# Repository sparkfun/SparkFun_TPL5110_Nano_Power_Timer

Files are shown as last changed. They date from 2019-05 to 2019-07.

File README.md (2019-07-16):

SparkFun TPL5110 Nano Power Timer
========================================

SparkFun Nano Power Switch

[*SparkFun Nano Power Switch (PRT-15353)*](https://www.sparkfun.com/products/15353)

Sometimes we want our projects on, but sometimes we want to turn them off for a while to save power. The SparkFun Nano Power Timer will run while only consuming minimal power (approximately 35nA) and turn your project on after a set amount of time. When you are done polling your sensors, posting data to the web, writing to your logger, or planning world domination, your microcontroller can tell the Nano Power Timer to turn off the power. No more running your microcontroller all day when you only want to read the ambient temperature once per hour.

Repository Contents
-------------------

* **/Documentation** - Data sheets, additional product information
* **/Firmware** - Example code 
* **/Hardware** - Eagle design files (.brd, .sch)
* **/Production** - Production panel files (.brd)

Documentation
--------------
* **[Hookup Guide](https://learn.sparkfun.com/tutorials/tpl5110-nano-power-timer-hookup-guide)** - Basic hookup guide for the TPL5110 Nano Power Timer.
* **[SparkFun Fritzing repo](https://github.com/sparkfun/Fritzing_Parts)** - Fritzing diagrams for SparkFun products.

License Information
-------------------
This product is _**open source**_! 

Please review the LICENSE.md file for license information. 

If you have any questions or concerns on licensing, please contact technical support on our [SparkFun forums](https://forum.sparkfun.com/viewforum.php?f=152).

Distributed as-is; no warranty is given.

- Your friends at SparkFun.

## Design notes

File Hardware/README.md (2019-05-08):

SparkFun Nano Power Switch Design Files
=====================================

The .sch and .brd files hare are Eagle CAD schematic and PCB design files from SparkFun Electronics.
A freeware version of Eagle can be found [here](http://www.cadsoftusa.com/download-eagle/freeware/).

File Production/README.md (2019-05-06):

SparkFun <PRODUCT NAME> Production Files
=========================================

These are the production files SparkFun uses for printing PCBs.

License Information
-------------------
This product is open source! 

The hardware is released under [Creative Commons ShareAlike 4.0 International](https://creativecommons.org/licenses/by-sa/4.0/).

Please use, reuse, and modify these files as you see fit. Please maintain attribution to SparkFun Electronics and release anything derivative under the same license.

Distributed as-is; no warranty is given.

- Your friends at SparkFun.

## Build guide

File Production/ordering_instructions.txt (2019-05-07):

panel size, 143x195mm
PCB thickness, 1.6mm
number of layers, 2
soldermask color, Red
silkscreen color, White
oz copper, 1oz
finish, HASL lead free
stencils, top+bottom
pcs per panel, 35
min trace width, 0.203200mm / 0.008000in
min drill size, 0.381000mm / 0.015000in

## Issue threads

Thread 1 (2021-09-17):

tpl5110 issue with time interval

MuhammadAsifSaeed, 2021-09-17:
Hello everyone!

I am using nano power timer according to the hookup guide of sparkfun for the last 2 years. Initially i was using it with arduino to increase the battery life and i had set the time interval 15 min. It worked fine, very fine.

this year i have a project and i am using tpl5110 with raspberry pi. nano power timer is supposed to wake up the raspberrry pi after 2 hours, but its not doing the job. Note: if set the time interval 15 min, it works fine.

Need your help.

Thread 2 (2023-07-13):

Revision Suggestion: Adding a Built-In Schottky Diode

bboyho, 2023-07-13:
### Subject of the issue
Users sometimes connect a second power source to their microcontroller's USB for uploading code without a Schottky diode between the Arduino's VIN and the TPL5110 's VOUT. The TPL5110 can be damaged from the conflicting voltages.

### Revision Suggestion
If there is time for a revision, it could be useful to add a built in Schottky diode on the VOUT line to prevent this from happening. Maybe add a jumper on the back for users that want to bypass the diode as well.

roblatour, 2023-08-11:
+1 for this recommendation

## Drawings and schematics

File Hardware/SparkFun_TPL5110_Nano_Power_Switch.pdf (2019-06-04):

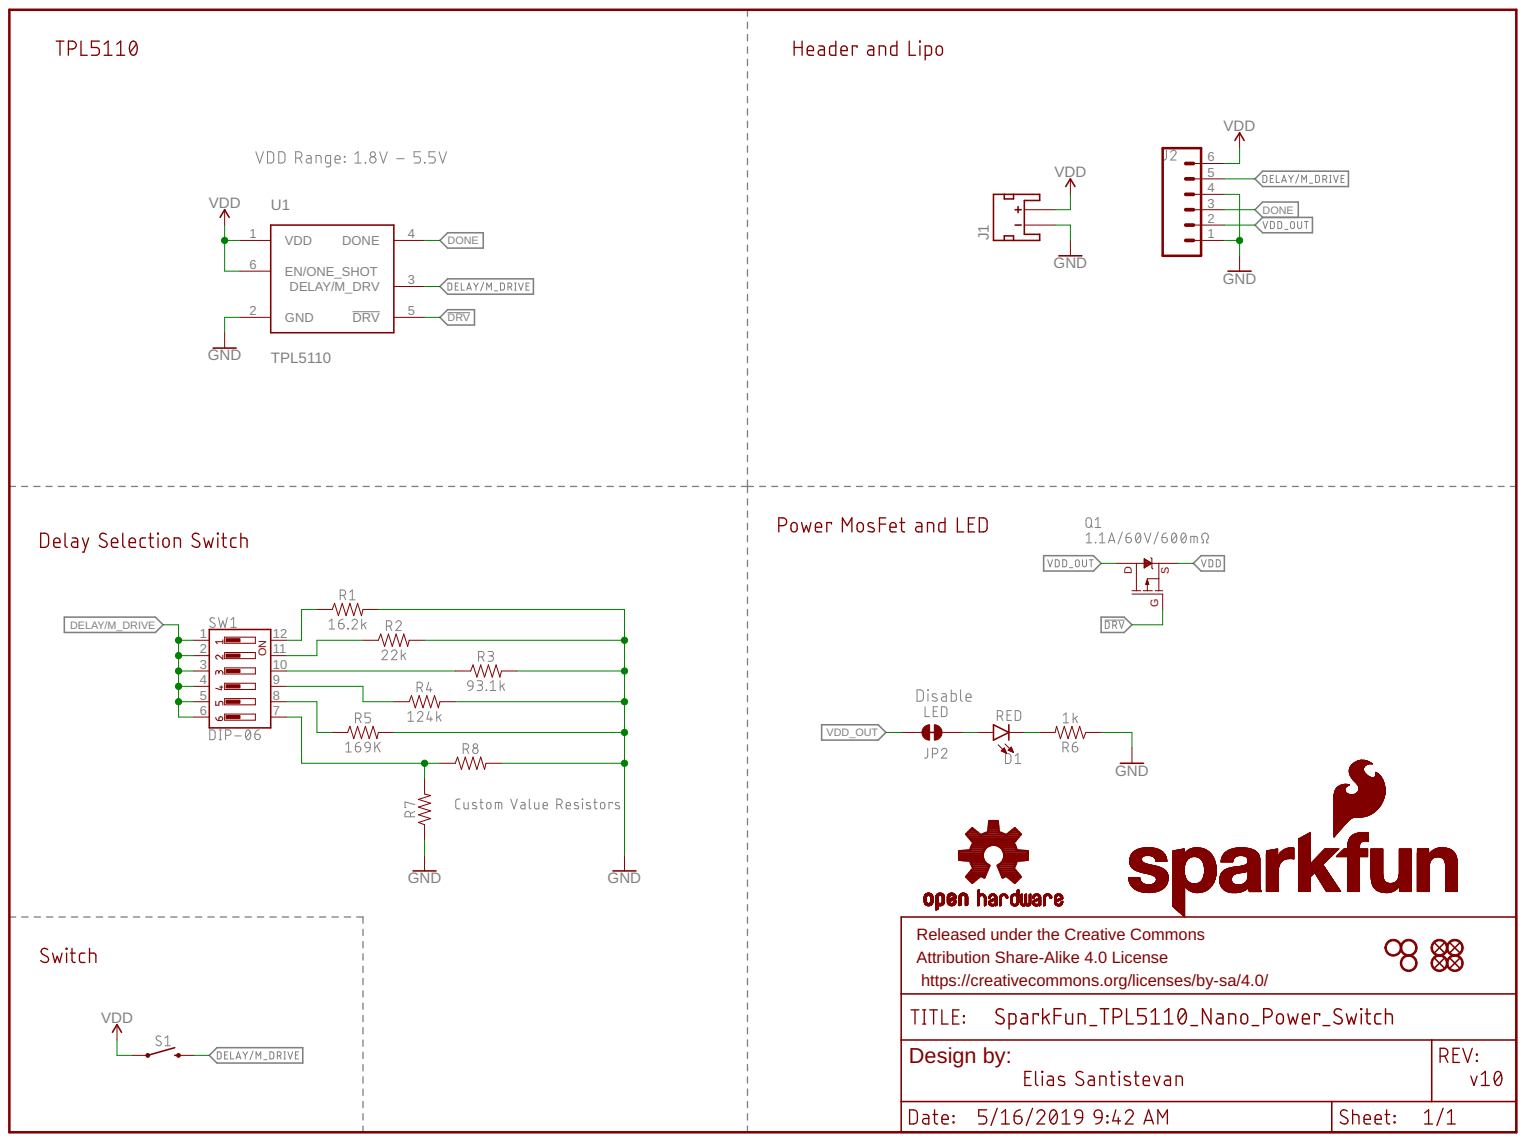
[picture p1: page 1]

Released under the Creative Commons
Attribution Share-Alike 4.0 License
https://creativecommons.org/licenses/by-sa/4.0/

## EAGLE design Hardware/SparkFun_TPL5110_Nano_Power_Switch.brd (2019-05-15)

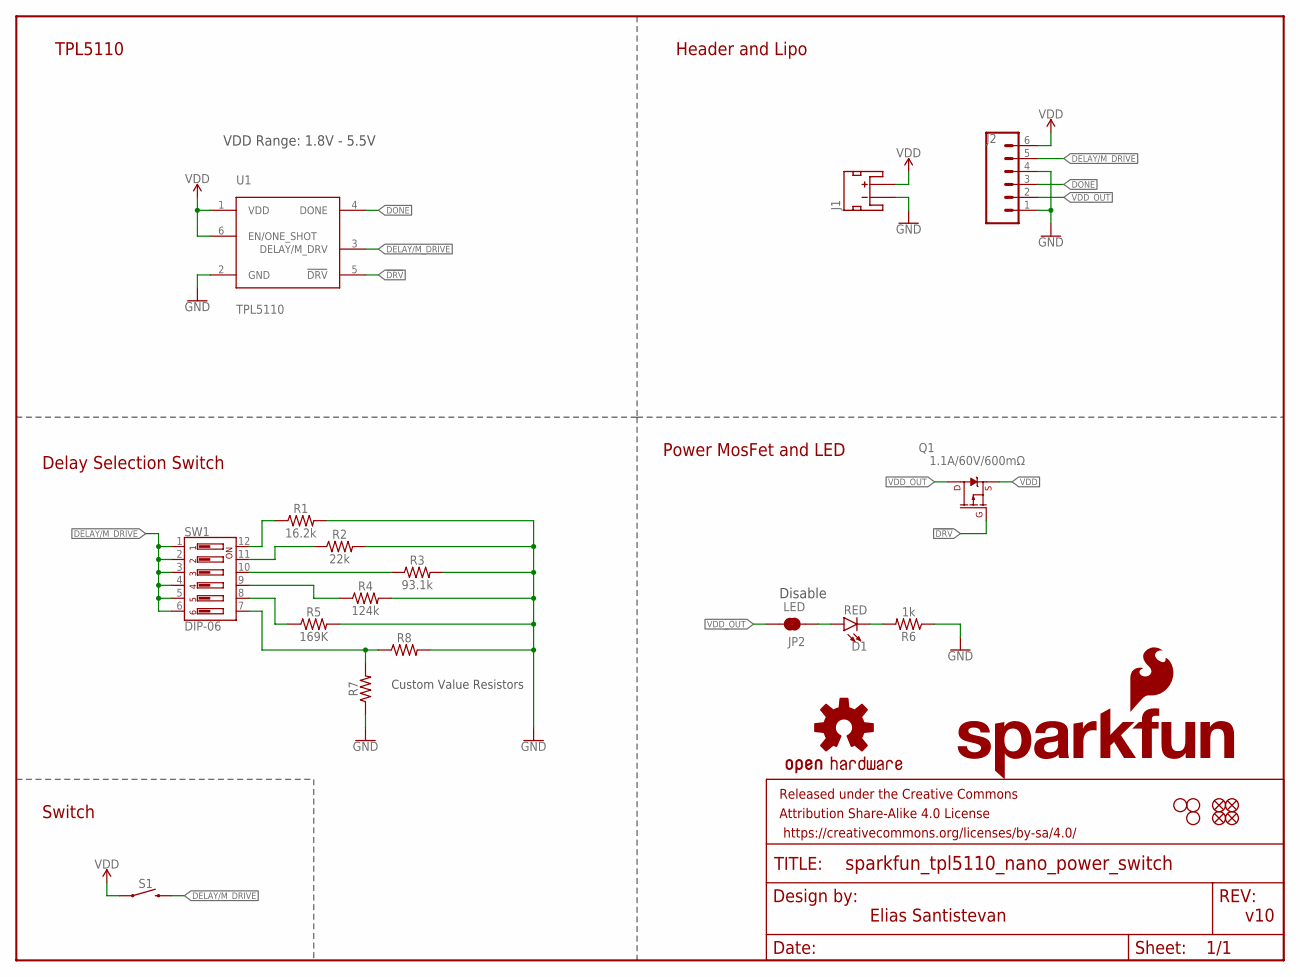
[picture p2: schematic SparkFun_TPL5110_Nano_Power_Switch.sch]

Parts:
D1: RED; LED-0603
FD1, FD2, FD3, FD4: FIDUCIALUFIDUCIAL; FIDUCIAL-MICRO
FRAME1: FRAME-LETTER; CREATIVE_COMMONS
H1, H2, H4: STAND-OFFTIGHT; STAND-OFF-TIGHT
J1: JST_2MM_MALE; JST-2-SMD
J2: CONN_06NO_SILK_NO_POP; 1X06_NO_SILK
JP2: LED; SMT-JUMPER_2_NC_TRACE_SILK
LOGO1: SFE_LOGO_NAME.1_INCH; SFE_LOGO_NAME_.1
LOGO2: OSHW-LOGOS; OSHW-LOGO-S
LOGO3: SFE_LOGO_FLAME.1_INCH; SFE_LOGO_FLAME_.1
Q1: 1.1A/60V/600mΩ; SOT23-3
R1: 16.2k; 0603
R2: 22k; 0603
R3: 93.1k; 0603
R4: 124k; 0603
R5: 169K; 0603
R6: 1k; 0603
R7: 0603
R8: AXIAL-0.3
S1: MOMENTARY-SWITCH-SPST-SMD-5.2MM-TALL; TACTILE_SWITCH_SMD_5.2MM
SW1: DIP-06; DIPSWITCH-06-SMD
U1: TPL5110; SOT23-6

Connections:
!DRV: Q1.1 (G), U1.5 (!DRV)
DELAY/M_DRIVE: J2.5, S1.3 (2), SW1.1, SW1.2, SW1.3, SW1.4, SW1.5, SW1.6, U1.3 (DELAY/M_DRV)
DONE: J2.3, U1.4 (DONE)
GND: J1.1 (-), J2.1, J2.4, R1.2, R2.2, R3.2, R4.2, R5.2, R6.1, R7.1, R8.P$2 (2), U1.2 (GND)
unnamed: D1.C, R6.2
unnamed: R1.1, SW1.12
unnamed: R2.1, SW1.11
unnamed: R3.1, SW1.10
unnamed: R4.1, SW1.9
unnamed: R5.1, SW1.8
unnamed: R7.2, R8.P$1 (1), SW1.7
unnamed: D1.A, JP2.1
VDD: J1.2 (+), J2.6, Q1.2 (S), S1.1, U1.1 (VDD), U1.6 (EN/ONE_SHOT)
VDD_OUT: J2.2, JP2.2, Q1.3 (D)

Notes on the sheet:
Elias Santistevan
v10
VDD Range: 1.8V - 5.5V
TPL5110
Header and Lipo
Power MosFet and LED
Delay Selection Switch
Switch
Disable
Custom Value Resistors

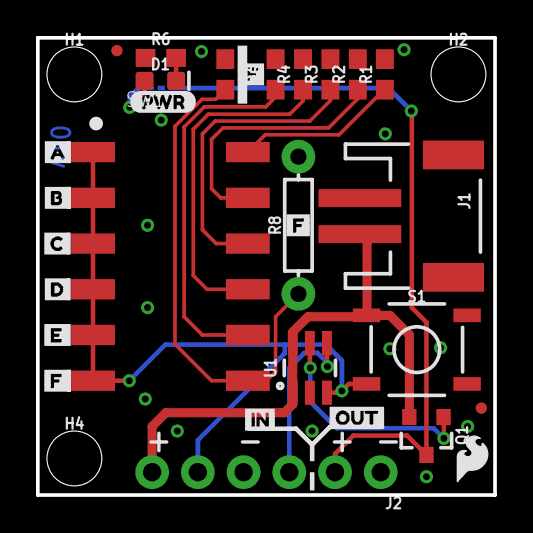
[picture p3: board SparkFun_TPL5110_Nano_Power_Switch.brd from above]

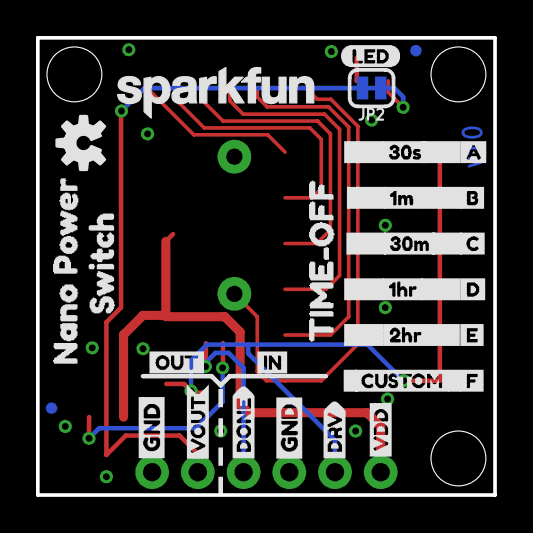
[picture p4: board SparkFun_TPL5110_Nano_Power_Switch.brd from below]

Board: 2 copper layers, 25.4 x 25.4 mm, 62 parts (29 on the bottom side), 14 nets.

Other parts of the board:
U$1: DONE0
U$2, U$4: GND-03
U$3: VOUT0
U$5: VDD0
U$6: NANO_POWER0
U$7: SWITCH0
U$8: 1M0
U$9: 30S4
U$10: 30M2
U$11: 1HR3
U$12: 2HR4
U$13: LED0
U$14: CUSTOM0
U$15: TIME#OFF0
U$16: DRV0
U$17, U$25: A0
U$18, U$26: B1
U$19, U$27: C2
U$20, U$28: D3
U$21, U$29: E4
U$22, U$23, U$24, U$30: F5
U$31, U$33: IN0
U$32, U$34: OUT1
U$35: PWR-()-03

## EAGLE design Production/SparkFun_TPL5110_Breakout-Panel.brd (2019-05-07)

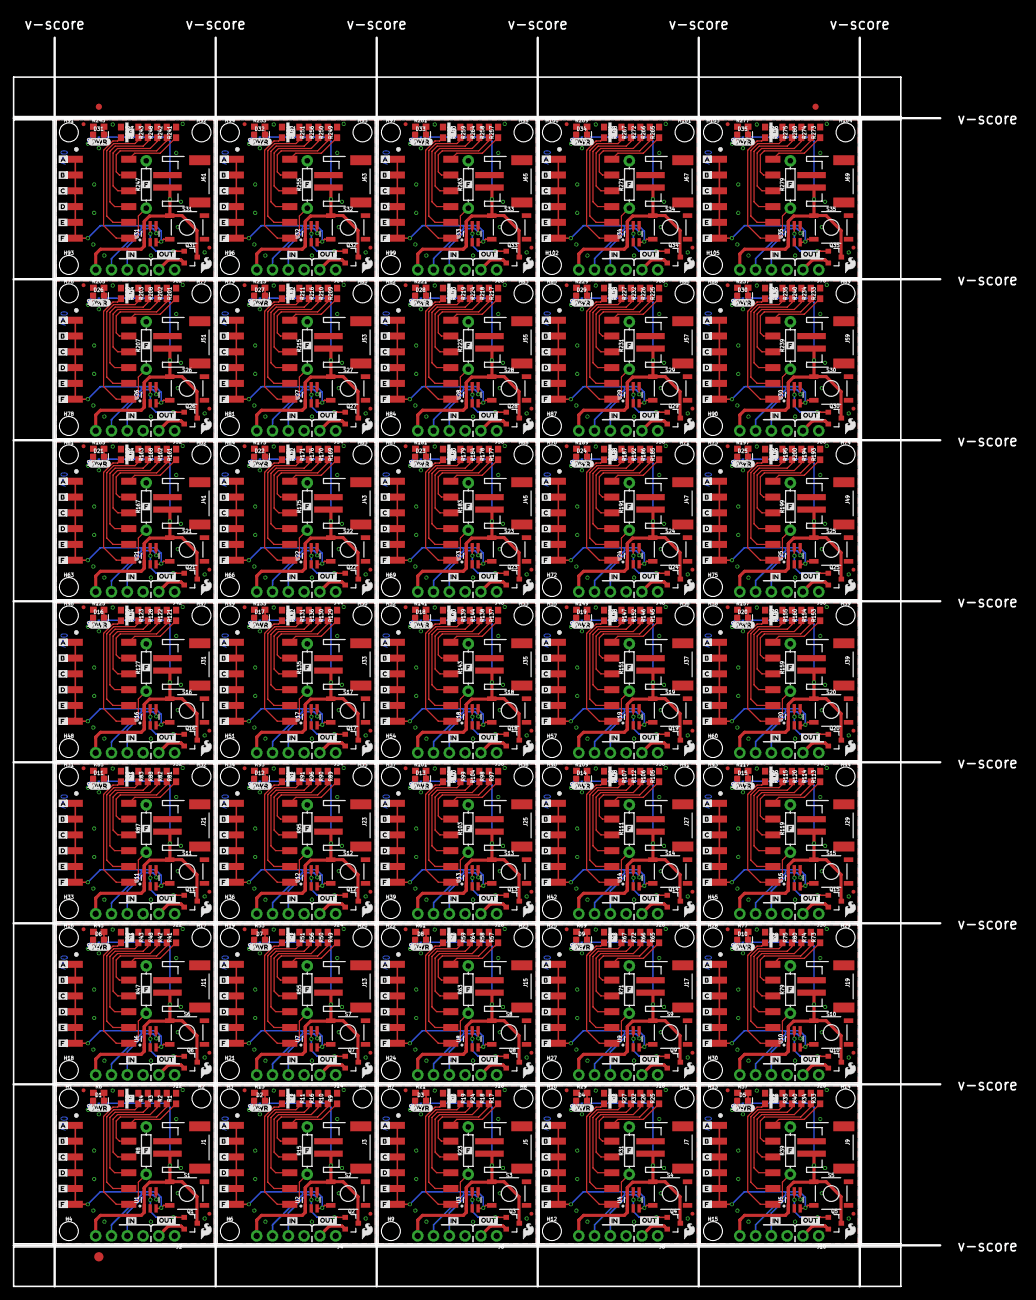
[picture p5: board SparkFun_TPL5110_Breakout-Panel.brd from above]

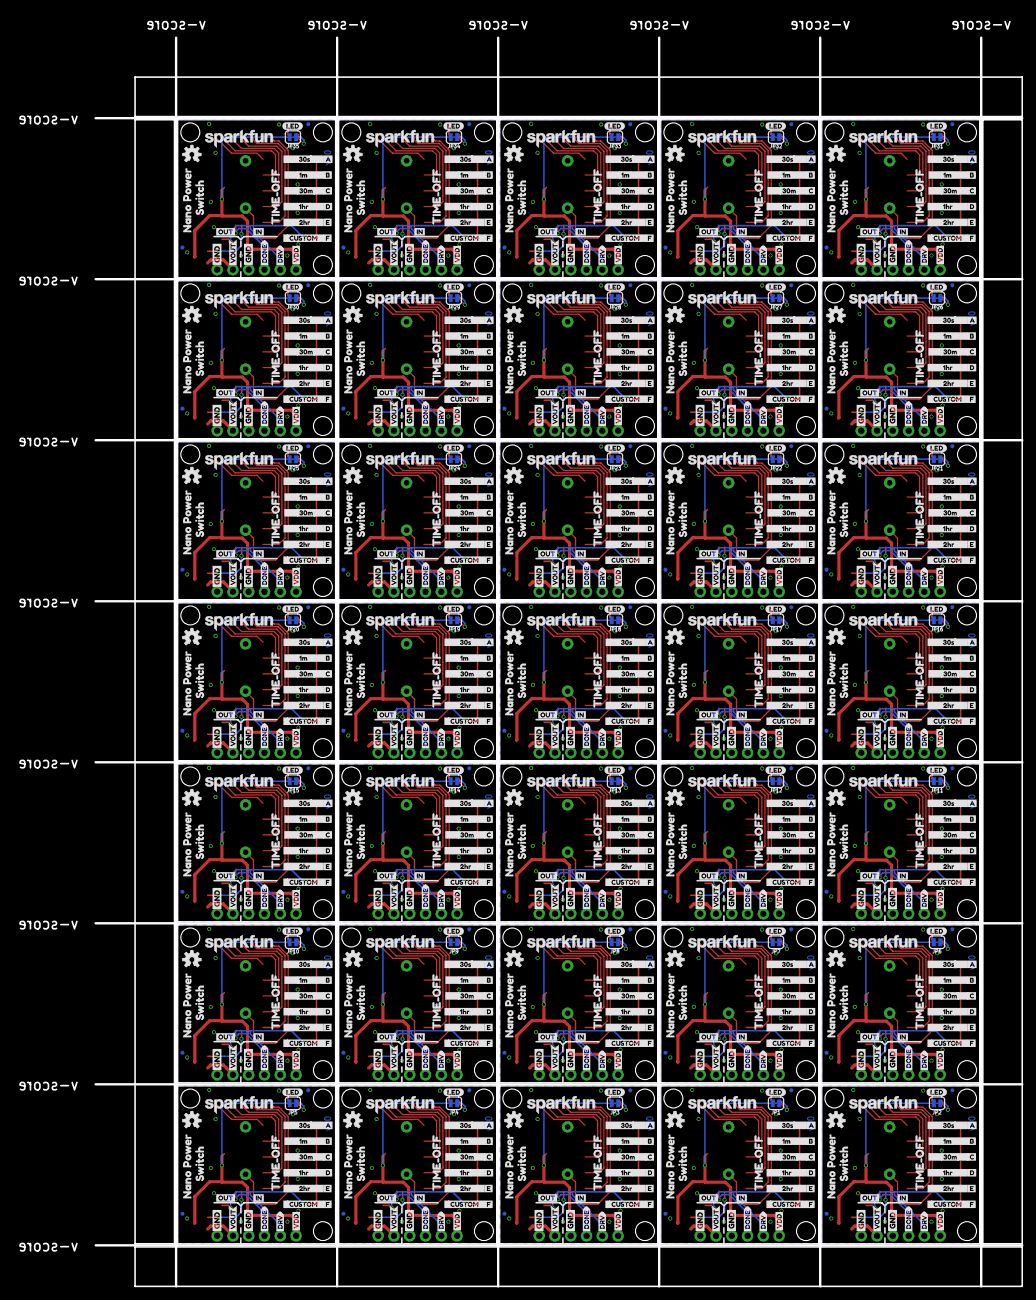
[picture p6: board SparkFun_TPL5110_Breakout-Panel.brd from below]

Board: 2 copper layers, 149.1 x 200.9 mm, 2138 parts (1015 on the bottom side), 490 nets.

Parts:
D1, D2, D3, D4, D5, D6, D7, D8, D9, D10, D11, D12, D13, D14, D15, D16, D17, D18, D19, D20, D21, D22, D23, D24, D25, D26, D27, D28, D29, D30, D31, D32, D33, D34, D35: RED; LED-0603
E$1, E$2: FIDUCIAL-1X2
E$3: FIDUCIAL-1.5X3
FD1, FD2, FD3, FD4, FD5, FD6, FD7, FD8, FD9, FD10, FD11, FD12, FD13, FD14, FD15, FD16, FD17, FD18, FD19, FD20, FD21, FD22, FD23, FD24, FD25, FD26, FD27, FD28, FD29, FD30, FD31, FD32, FD33, FD34, FD35, FD36, FD37, FD38, FD39, FD40, FD41, FD42, FD43, FD44, FD45, FD46, FD47, FD48, FD49, FD50, FD51, FD52, FD53, FD54, FD55, FD56, FD57, FD58, FD59, FD60, FD61, FD62, FD63, FD64, FD65, FD66, FD67, FD68, FD69, FD70, FD71, FD72, FD73, FD74, FD75, FD76, FD77, FD78, FD79, FD80, FD81, FD82, FD83, FD84, FD85, FD86, FD87, FD88, FD89, FD90, FD91, FD92, FD93, FD94, FD95, FD96, FD97, FD98, FD99, FD100, FD101, FD102, FD103, FD104, FD105, FD106, FD107, FD108, FD109, FD110, FD111, FD112, FD113, FD114, FD115, FD116, FD117, FD118, FD119, FD120, FD121, FD122, FD123, FD124, FD125, FD126, FD127, FD128, FD129, FD130, FD131, FD132, FD133, FD134, FD135, FD136, FD137, FD138, FD139, FD140: FIDUCIALUFIDUCIAL; FIDUCIAL-MICRO
H1, H2, H3, H4, H5, H6, H7, H8, H9, H10, H11, H12, H13, H14, H15, H16, H17, H18, H19, H20, H21, H22, H23, H24, H25, H26, H27, H28, H29, H30, H31, H32, H33, H34, H35, H36, H37, H38, H39, H40, H41, H42, H43, H44, H45, H46, H47, H48, H49, H50, H51, H52, H53, H54, H55, H56, H57, H58, H59, H60, H61, H62, H63, H64, H65, H66, H67, H68, H69, H70, H71, H72, H73, H74, H75, H76, H77, H78, H79, H80, H81, H82, H83, H84, H85, H86, H87, H88, H89, H90, H91, H92, H93, H94, H95, H96, H97, H98, H99, H100, H101, H102, H103, H104, H105: STAND-OFFTIGHT; STAND-OFF-TIGHT
J1, J3, J5, J7, J9, J11, J13, J15, J17, J19, J21, J23, J25, J27, J29, J31, J33, J35, J37, J39, J41, J43, J45, J47, J49, J51, J53, J55, J57, J59, J61, J63, J65, J67, J69: JST-2-SMD
J2, J4, J6, J8, J10, J12, J14, J16, J18, J20, J22, J24, J26, J28, J30, J32, J34, J36, J38, J40, J42, J44, J46, J48, J50, J52, J54, J56, J58, J60, J62, J64, J66, J68, J70: 1X06_NO_SILK
JP1, JP2, JP3, JP4, JP5, JP6, JP7, JP8, JP9, JP10, JP11, JP12, JP13, JP14, JP15, JP16, JP17, JP18, JP19, JP20, JP21, JP22, JP23, JP24, JP25, JP26, JP27, JP28, JP29, JP30, JP31, JP32, JP33, JP34, JP35: LED; SMT-JUMPER_2_NC_TRACE_SILK
LOGO1, LOGO4, LOGO7, LOGO10, LOGO13, LOGO16, LOGO19, LOGO22, LOGO25, LOGO28, LOGO31, LOGO34, LOGO37, LOGO40, LOGO43, LOGO46, LOGO49, LOGO52, LOGO55, LOGO58, LOGO61, LOGO64, LOGO67, LOGO70, LOGO73, LOGO76, LOGO79, LOGO82, LOGO85, LOGO88, LOGO91, LOGO94, LOGO97, LOGO100, LOGO103: SFE_LOGO_NAME.1_INCH; SFE_LOGO_NAME_.1
LOGO2, LOGO5, LOGO8, LOGO11, LOGO14, LOGO17, LOGO20, LOGO23, LOGO26, LOGO29, LOGO32, LOGO35, LOGO38, LOGO41, LOGO44, LOGO47, LOGO50, LOGO53, LOGO56, LOGO59, LOGO62, LOGO65, LOGO68, LOGO71, LOGO74, LOGO77, LOGO80, LOGO83, LOGO86, LOGO89, LOGO92, LOGO95, LOGO98, LOGO101, LOGO104: OSHW-LOGOS; OSHW-LOGO-S
LOGO3, LOGO6, LOGO9, LOGO12, LOGO15, LOGO18, LOGO21, LOGO24, LOGO27, LOGO30, LOGO33, LOGO36, LOGO39, LOGO42, LOGO45, LOGO48, LOGO51, LOGO54, LOGO57, LOGO60, LOGO63, LOGO66, LOGO69, LOGO72, LOGO75, LOGO78, LOGO81, LOGO84, LOGO87, LOGO90, LOGO93, LOGO96, LOGO99, LOGO102, LOGO105: SFE_LOGO_FLAME.1_INCH; SFE_LOGO_FLAME_.1
Q1, Q2, Q3, Q4, Q5, Q6, Q7, Q8, Q9, Q10, Q11, Q12, Q13, Q14, Q15, Q16, Q17, Q18, Q19, Q20, Q21, Q22, Q23, Q24, Q25, Q26, Q27, Q28, Q29, Q30, Q31, Q32, Q33, Q34, Q35: 1.1A/60V/600mΩ; SOT23-3
R1, R9, R17, R25, R33, R41, R49, R57, R65, R73, R81, R89, R97, R105, R113, R121, R129, R137, R145, R153, R161, R169, R177, R185, R193, R201, R209, R217, R225, R233, R241, R249, R257, R265, R273: 16.2k; 0603
R2, R10, R18, R26, R34, R42, R50, R58, R66, R74, R82, R90, R98, R106, R114, R122, R130, R138, R146, R154, R162, R170, R178, R186, R194, R202, R210, R218, R226, R234, R242, R250, R258, R266, R274: 22k; 0603
R3, R16, R24, R32, R40, R48, R56, R64, R72, R80, R88, R96, R104, R112, R120, R128, R136, R144, R152, R160, R168, R176, R184, R192, R200, R208, R216, R224, R232, R240, R248, R256, R264, R272, R280: 93.1k; 0603
R4, R11, R19, R27, R35, R43, R51, R59, R67, R75, R83, R91, R99, R107, R115, R123, R131, R139, R147, R155, R163, R171, R179, R187, R195, R203, R211, R219, R227, R235, R243, R251, R259, R267, R275: 124k; 0603
R5, R12, R20, R28, R36, R44, R52, R60, R68, R76, R84, R92, R100, R108, R116, R124, R132, R140, R148, R156, R164, R172, R180, R188, R196, R204, R212, R220, R228, R236, R244, R252, R260, R268, R276: 169K; 0603
R6, R13, R21, R29, R37, R45, R53, R61, R69, R77, R85, R93, R101, R109, R117, R125, R133, R141, R149, R157, R165, R173, R181, R189, R197, R205, R213, R221, R229, R237, R245, R253, R261, R269, R277: 330; 0603
R7, R14, R22, R30, R38, R46, R54, R62, R70, R78, R86, R94, R102, R110, R118, R126, R134, R142, R150, R158, R166, R174, R182, R190, R198, R206, R214, R222, R230, R238, R246, R254, R262, R270, R278: 0603
R8, R15, R23, R31, R39, R47, R55, R63, R71, R79, R87, R95, R103, R111, R119, R127, R135, R143, R151, R159, R167, R175, R183, R191, R199, R207, R215, R223, R231, R239, R247, R255, R263, R271, R279: AXIAL-0.3
S1, S2, S3, S4, S5, S6, S7, S8, S9, S10, S11, S12, S13, S14, S15, S16, S17, S18, S19, S20, S21, S22, S23, S24, S25, S26, S27, S28, S29, S30, S31, S32, S33, S34, S35: MOMENTARY-SWITCH-SPST-SMD-5.2MM-TALL; TACTILE_SWITCH_SMD_5.2MM
SW1, SW2, SW3, SW4, SW5, SW6, SW7, SW8, SW9, SW10, SW11, SW12, SW13, SW14, SW15, SW16, SW17, SW18, SW19, SW20, SW21, SW22, SW23, SW24, SW25, SW26, SW27, SW28, SW29, SW30, SW31, SW32, SW33, SW34, SW35: DIP-06; DIPSWITCH-06-SMD
U1, U2, U3, U4, U5, U6, U7, U8, U9, U10, U11, U12, U13, U14, U15, U16, U17, U18, U19, U20, U21, U22, U23, U24, U25, U26, U27, U28, U29, U30, U31, U32, U33, U34, U35: TPL5110; SOT23-6
U$1, U$42, U$77, U$112, U$147, U$182, U$217, U$252, U$287, U$322, U$357, U$392, U$427, U$462, U$497, U$532, U$567, U$602, U$637, U$672, U$707, U$742, U$777, U$812, U$847, U$882, U$917, U$952, U$987, U$1022, U$1057, U$1092, U$1127, U$1162, U$1197: DONE0
U$2, U$4, U$36, U$38, U$71, U$73, U$106, U$108, U$141, U$143, U$176, U$178, U$211, U$213, U$246, U$248, U$281, U$283, U$316, U$318, U$351, U$353, U$386, U$388, U$421, U$423, U$456, U$458, U$491, U$493, U$526, U$528, U$561, U$563, U$596, U$598, U$631, U$633, U$666, U$668, U$701, U$703, U$736, U$738, U$771, U$773, U$806, U$808, U$841, U$843, U$876, U$878, U$911, U$913, U$946, U$948, U$981, U$983, U$1016, U$1018, U$1051, U$1053, U$1086, U$1088, U$1121, U$1123, U$1156, U$1158, U$1191, U$1193: GND-03
U$3, U$43, U$78, U$113, U$148, U$183, U$218, U$253, U$288, U$323, U$358, U$393, U$428, U$463, U$498, U$533, U$568, U$603, U$638, U$673, U$708, U$743, U$778, U$813, U$848, U$883, U$918, U$953, U$988, U$1023, U$1058, U$1093, U$1128, U$1163, U$1198: VOUT0
U$5, U$37, U$72, U$107, U$142, U$177, U$212, U$247, U$282, U$317, U$352, U$387, U$422, U$457, U$492, U$527, U$562, U$597, U$632, U$667, U$702, U$737, U$772, U$807, U$842, U$877, U$912, U$947, U$982, U$1017, U$1052, U$1087, U$1122, U$1157, U$1192: VDD0
U$6, U$68, U$103, U$138, U$173, U$208, U$243, U$278, U$313, U$348, U$383, U$418, U$453, U$488, U$523, U$558, U$593, U$628, U$663, U$698, U$733, U$768, U$803, U$838, U$873, U$908, U$943, U$978, U$1013, U$1048, U$1083, U$1118, U$1153, U$1188, U$1223: NANO_POWER0
U$7, U$69, U$104, U$139, U$174, U$209, U$244, U$279, U$314, U$349, U$384, U$419, U$454, U$489, U$524, U$559, U$594, U$629, U$664, U$699, U$734, U$769, U$804, U$839, U$874, U$909, U$944, U$979, U$1014, U$1049, U$1084, U$1119, U$1154, U$1189, U$1224: SWITCH0
U$8, U$59, U$94, U$129, U$164, U$199, U$234, U$269, U$304, U$339, U$374, U$409, U$444, U$479, U$514, U$549, U$584, U$619, U$654, U$689, U$724, U$759, U$794, U$829, U$864, U$899, U$934, U$969, U$1004, U$1039, U$1074, U$1109, U$1144, U$1179, U$1214: 1M0
U$9, U$63, U$98, U$133, U$168, U$203, U$238, U$273, U$308, U$343, U$378, U$413, U$448, U$483, U$518, U$553, U$588, U$623, U$658, U$693, U$728, U$763, U$798, U$833, U$868, U$903, U$938, U$973, U$1008, U$1043, U$1078, U$1113, U$1148, U$1183, U$1218: 30S4
U$10, U$60, U$95, U$130, U$165, U$200, U$235, U$270, U$305, U$340, U$375, U$410, U$445, U$480, U$515, U$550, U$585, U$620, U$655, U$690, U$725, U$760, U$795, U$830, U$865, U$900, U$935, U$970, U$1005, U$1040, U$1075, U$1110, U$1145, U$1180, U$1215: 30M2
U$11, U$61, U$96, U$131, U$166, U$201, U$236, U$271, U$306, U$341, U$376, U$411, U$446, U$481, U$516, U$551, U$586, U$621, U$656, U$691, U$726, U$761, U$796, U$831, U$866, U$901, U$936, U$971, U$1006, U$1041, U$1076, U$1111, U$1146, U$1181, U$1216: 1HR3
U$12, U$62, U$97, U$132, U$167, U$202, U$237, U$272, U$307, U$342, U$377, U$412, U$447, U$482, U$517, U$552, U$587, U$622, U$657, U$692, U$727, U$762, U$797, U$832, U$867, U$902, U$937, U$972, U$1007, U$1042, U$1077, U$1112, U$1147, U$1182, U$1217: 2HR4
U$13, U$40, U$75, U$110, U$145, U$180, U$215, U$250, U$285, U$320, U$355, U$390, U$425, U$460, U$495, U$530, U$565, U$600, U$635, U$670, U$705, U$740, U$775, U$810, U$845, U$880, U$915, U$950, U$985, U$1020, U$1055, U$1090, U$1125, U$1160, U$1195: LED0
U$14, U$39, U$74, U$109, U$144, U$179, U$214, U$249, U$284, U$319, U$354, U$389, U$424, U$459, U$494, U$529, U$564, U$599, U$634, U$669, U$704, U$739, U$774, U$809, U$844, U$879, U$914, U$949, U$984, U$1019, U$1054, U$1089, U$1124, U$1159, U$1194: CUSTOM0
U$15, U$41, U$76, U$111, U$146, U$181, U$216, U$251, U$286, U$321, U$356, U$391, U$426, U$461, U$496, U$531, U$566, U$601, U$636, U$671, U$706, U$741, U$776, U$811, U$846, U$881, U$916, U$951, U$986, U$1021, U$1056, U$1091, U$1126, U$1161, U$1196: TIME#OFF0
U$16, U$44, U$79, U$114, U$149, U$184, U$219, U$254, U$289, U$324, U$359, U$394, U$429, U$464, U$499, U$534, U$569, U$604, U$639, U$674, U$709, U$744, U$779, U$814, U$849, U$884, U$919, U$954, U$989, U$1024, U$1059, U$1094, U$1129, U$1164, U$1199: DRV0
U$17, U$25, U$45, U$53, U$80, U$88, U$115, U$123, U$150, U$158, U$185, U$193, U$220, U$228, U$255, U$263, U$290, U$298, U$325, U$333, U$360, U$368, U$395, U$403, U$430, U$438, U$465, U$473, U$500, U$508, U$535, U$543, U$570, U$578, U$605, U$613, U$640, U$648, U$675, U$683, U$710, U$718, U$745, U$753, U$780, U$788, U$815, U$823, U$850, U$858, U$885, U$893, U$920, U$928, U$955, U$963, U$990, U$998, U$1025, U$1033, U$1060, U$1068, U$1095, U$1103, U$1130, U$1138, U$1165, U$1173, U$1200, U$1208: A0
U$18, U$26, U$46, U$54, U$81, U$89, U$116, U$124, U$151, U$159, U$186, U$194, U$221, U$229, U$256, U$264, U$291, U$299, U$326, U$334, U$361, U$369, U$396, U$404, U$431, U$439, U$466, U$474, U$501, U$509, U$536, U$544, U$571, U$579, U$606, U$614, U$641, U$649, U$676, U$684, U$711, U$719, U$746, U$754, U$781, U$789, U$816, U$824, U$851, U$859, U$886, U$894, U$921, U$929, U$956, U$964, U$991, U$999, U$1026, U$1034, U$1061, U$1069, U$1096, U$1104, U$1131, U$1139, U$1166, U$1174, U$1201, U$1209: B1
U$19, U$27, U$47, U$55, U$82, U$90, U$117, U$125, U$152, U$160, U$187, U$195, U$222, U$230, U$257, U$265, U$292, U$300, U$327, U$335, U$362, U$370, U$397, U$405, U$432, U$440, U$467, U$475, U$502, U$510, U$537, U$545, U$572, U$580, U$607, U$615, U$642, U$650, U$677, U$685, U$712, U$720, U$747, U$755, U$782, U$790, U$817, U$825, U$852, U$860, U$887, U$895, U$922, U$930, U$957, U$965, U$992, U$1000, U$1027, U$1035, U$1062, U$1070, U$1097, U$1105, U$1132, U$1140, U$1167, U$1175, U$1202, U$1210: C2
U$20, U$28, U$48, U$56, U$83, U$91, U$118, U$126, U$153, U$161, U$188, U$196, U$223, U$231, U$258, U$266, U$293, U$301, U$328, U$336, U$363, U$371, U$398, U$406, U$433, U$441, U$468, U$476, U$503, U$511, U$538, U$546, U$573, U$581, U$608, U$616, U$643, U$651, U$678, U$686, U$713, U$721, U$748, U$756, U$783, U$791, U$818, U$826, U$853, U$861, U$888, U$896, U$923, U$931, U$958, U$966, U$993, U$1001, U$1028, U$1036, U$1063, U$1071, U$1098, U$1106, U$1133, U$1141, U$1168, U$1176, U$1203, U$1211: D3
U$21, U$29, U$49, U$57, U$84, U$92, U$119, U$127, U$154, U$162, U$189, U$197, U$224, U$232, U$259, U$267, U$294, U$302, U$329, U$337, U$364, U$372, U$399, U$407, U$434, U$442, U$469, U$477, U$504, U$512, U$539, U$547, U$574, U$582, U$609, U$617, U$644, U$652, U$679, U$687, U$714, U$722, U$749, U$757, U$784, U$792, U$819, U$827, U$854, U$862, U$889, U$897, U$924, U$932, U$959, U$967, U$994, U$1002, U$1029, U$1037, U$1064, U$1072, U$1099, U$1107, U$1134, U$1142, U$1169, U$1177, U$1204, U$1212: E4
U$22, U$23, U$24, U$30, U$50, U$51, U$52, U$58, U$85, U$86, U$87, U$93, U$120, U$121, U$122, U$128, U$155, U$156, U$157, U$163, U$190, U$191, U$192, U$198, U$225, U$226, U$227, U$233, U$260, U$261, U$262, U$268, U$295, U$296, U$297, U$303, U$330, U$331, U$332, U$338, U$365, U$366, U$367, U$373, U$400, U$401, U$402, U$408, U$435, U$436, U$437, U$443, U$470, U$471, U$472, U$478, U$505, U$506, U$507, U$513, U$540, U$541, U$542, U$548, U$575, U$576, U$577, U$583, U$610, U$611, U$612, U$618, U$645, U$646, U$647, U$653, U$680, U$681, U$682, U$688, U$715, U$716, U$717, U$723, U$750, U$751, U$752, U$758, U$785, U$786, U$787, U$793, U$820, U$821, U$822, U$828, U$855, U$856, U$857, U$863, U$890, U$891, U$892, U$898, U$925, U$926, U$927, U$933, U$960, U$961, U$962, U$968, U$995, U$996, U$997, U$1003, U$1030, U$1031, U$1032, U$1038, U$1065, U$1066, U$1067, U$1073, U$1100, U$1101, U$1102, U$1108, U$1135, U$1136, U$1137, U$1143, U$1170, U$1171, U$1172, U$1178, U$1205, U$1206, U$1207, U$1213: F5
U$31, U$33, U$64, U$66, U$99, U$101, U$134, U$136, U$169, U$171, U$204, U$206, U$239, U$241, U$274, U$276, U$309, U$311, U$344, U$346, U$379, U$381, U$414, U$416, U$449, U$451, U$484, U$486, U$519, U$521, U$554, U$556, U$589, U$591, U$624, U$626, U$659, U$661, U$694, U$696, U$729, U$731, U$764, U$766, U$799, U$801, U$834, U$836, U$869, U$871, U$904, U$906, U$939, U$941, U$974, U$976, U$1009, U$1011, U$1044, U$1046, U$1079, U$1081, U$1114, U$1116, U$1149, U$1151, U$1184, U$1186, U$1219, U$1221: IN0
U$32, U$34, U$65, U$67, U$100, U$102, U$135, U$137, U$170, U$172, U$205, U$207, U$240, U$242, U$275, U$277, U$310, U$312, U$345, U$347, U$380, U$382, U$415, U$417, U$450, U$452, U$485, U$487, U$520, U$522, U$555, U$557, U$590, U$592, U$625, U$627, U$660, U$662, U$695, U$697, U$730, U$732, U$765, U$767, U$800, U$802, U$835, U$837, U$870, U$872, U$905, U$907, U$940, U$942, U$975, U$977, U$1010, U$1012, U$1045, U$1047, U$1080, U$1082, U$1115, U$1117, U$1150, U$1152, U$1185, U$1187, U$1220, U$1222: OUT1
U$35, U$70, U$105, U$140, U$175, U$210, U$245, U$280, U$315, U$350, U$385, U$420, U$455, U$490, U$525, U$560, U$595, U$630, U$665, U$700, U$735, U$770, U$805, U$840, U$875, U$910, U$945, U$980, U$1015, U$1050, U$1085, U$1120, U$1155, U$1190, U$1225: PWR-()-03

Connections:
!DRV: Q1.1, U1.5
!DRV1: Q2.1, U2.5
!DRV2: Q3.1, U3.5
!DRV3: Q4.1, U4.5
!DRV4: Q5.1, U5.5
!DRV5: Q6.1, U6.5
!DRV6: Q7.1, U7.5
!DRV7: Q8.1, U8.5
!DRV8: Q9.1, U9.5
!DRV9: Q10.1, U10.5
!DRV10: Q11.1, U11.5
!DRV11: Q12.1, U12.5
!DRV12: Q13.1, U13.5
!DRV13: Q14.1, U14.5
!DRV14: Q15.1, U15.5
!DRV15: Q16.1, U16.5
!DRV16: Q17.1, U17.5
!DRV17: Q18.1, U18.5
!DRV18: Q19.1, U19.5
!DRV19: Q20.1, U20.5
!DRV20: Q21.1, U21.5
!DRV21: Q22.1, U22.5
!DRV22: Q23.1, U23.5
!DRV23: Q24.1, U24.5
!DRV24: Q25.1, U25.5
!DRV25: Q26.1, U26.5
!DRV26: Q27.1, U27.5
!DRV27: Q28.1, U28.5
!DRV28: Q29.1, U29.5
!DRV29: Q30.1, U30.5
!DRV30: Q31.1, U31.5
!DRV31: Q32.1, U32.5
!DRV32: Q33.1, U33.5
!DRV33: Q34.1, U34.5
!DRV34: Q35.1, U35.5
DELAY/M_DRIVE: J2.5, S1.3, SW1.1, SW1.2, SW1.3, SW1.4, SW1.5, SW1.6, U1.3
DELAY/M_DRIVE1: J4.5, S2.3, SW2.1, SW2.2, SW2.3, SW2.4, SW2.5, SW2.6, U2.3
DELAY/M_DRIVE2: J6.5, S3.3, SW3.1, SW3.2, SW3.3, SW3.4, SW3.5, SW3.6, U3.3
DELAY/M_DRIVE3: J8.5, S4.3, SW4.1, SW4.2, SW4.3, SW4.4, SW4.5, SW4.6, U4.3
DELAY/M_DRIVE4: J10.5, S5.3, SW5.1, SW5.2, SW5.3, SW5.4, SW5.5, SW5.6, U5.3
DELAY/M_DRIVE5: J12.5, S6.3, SW6.1, SW6.2, SW6.3, SW6.4, SW6.5, SW6.6, U6.3
DELAY/M_DRIVE6: J14.5, S7.3, SW7.1, SW7.2, SW7.3, SW7.4, SW7.5, SW7.6, U7.3
DELAY/M_DRIVE7: J16.5, S8.3, SW8.1, SW8.2, SW8.3, SW8.4, SW8.5, SW8.6, U8.3
DELAY/M_DRIVE8: J18.5, S9.3, SW9.1, SW9.2, SW9.3, SW9.4, SW9.5, SW9.6, U9.3
DELAY/M_DRIVE9: J20.5, S10.3, SW10.1, SW10.2, SW10.3, SW10.4, SW10.5, SW10.6, U10.3
DELAY/M_DRIVE10: J22.5, S11.3, SW11.1, SW11.2, SW11.3, SW11.4, SW11.5, SW11.6, U11.3
DELAY/M_DRIVE11: J24.5, S12.3, SW12.1, SW12.2, SW12.3, SW12.4, SW12.5, SW12.6, U12.3
DELAY/M_DRIVE12: J26.5, S13.3, SW13.1, SW13.2, SW13.3, SW13.4, SW13.5, SW13.6, U13.3
DELAY/M_DRIVE13: J28.5, S14.3, SW14.1, SW14.2, SW14.3, SW14.4, SW14.5, SW14.6, U14.3
DELAY/M_DRIVE14: J30.5, S15.3, SW15.1, SW15.2, SW15.3, SW15.4, SW15.5, SW15.6, U15.3
DELAY/M_DRIVE15: J32.5, S16.3, SW16.1, SW16.2, SW16.3, SW16.4, SW16.5, SW16.6, U16.3
DELAY/M_DRIVE16: J34.5, S17.3, SW17.1, SW17.2, SW17.3, SW17.4, SW17.5, SW17.6, U17.3
DELAY/M_DRIVE17: J36.5, S18.3, SW18.1, SW18.2, SW18.3, SW18.4, SW18.5, SW18.6, U18.3
DELAY/M_DRIVE18: J38.5, S19.3, SW19.1, SW19.2, SW19.3, SW19.4, SW19.5, SW19.6, U19.3
DELAY/M_DRIVE19: J40.5, S20.3, SW20.1, SW20.2, SW20.3, SW20.4, SW20.5, SW20.6, U20.3
DELAY/M_DRIVE20: J42.5, S21.3, SW21.1, SW21.2, SW21.3, SW21.4, SW21.5, SW21.6, U21.3
DELAY/M_DRIVE21: J44.5, S22.3, SW22.1, SW22.2, SW22.3, SW22.4, SW22.5, SW22.6, U22.3
DELAY/M_DRIVE22: J46.5, S23.3, SW23.1, SW23.2, SW23.3, SW23.4, SW23.5, SW23.6, U23.3
DELAY/M_DRIVE23: J48.5, S24.3, SW24.1, SW24.2, SW24.3, SW24.4, SW24.5, SW24.6, U24.3
DELAY/M_DRIVE24: J50.5, S25.3, SW25.1, SW25.2, SW25.3, SW25.4, SW25.5, SW25.6, U25.3
DELAY/M_DRIVE25: J52.5, S26.3, SW26.1, SW26.2, SW26.3, SW26.4, SW26.5, SW26.6, U26.3
DELAY/M_DRIVE26: J54.5, S27.3, SW27.1, SW27.2, SW27.3, SW27.4, SW27.5, SW27.6, U27.3
DELAY/M_DRIVE27: J56.5, S28.3, SW28.1, SW28.2, SW28.3, SW28.4, SW28.5, SW28.6, U28.3
DELAY/M_DRIVE28: J58.5, S29.3, SW29.1, SW29.2, SW29.3, SW29.4, SW29.5, SW29.6, U29.3
DELAY/M_DRIVE29: J60.5, S30.3, SW30.1, SW30.2, SW30.3, SW30.4, SW30.5, SW30.6, U30.3
DELAY/M_DRIVE30: J62.5, S31.3, SW31.1, SW31.2, SW31.3, SW31.4, SW31.5, SW31.6, U31.3
DELAY/M_DRIVE31: J64.5, S32.3, SW32.1, SW32.2, SW32.3, SW32.4, SW32.5, SW32.6, U32.3
DELAY/M_DRIVE32: J66.5, S33.3, SW33.1, SW33.2, SW33.3, SW33.4, SW33.5, SW33.6, U33.3
DELAY/M_DRIVE33: J68.5, S34.3, SW34.1, SW34.2, SW34.3, SW34.4, SW34.5, SW34.6, U34.3
DELAY/M_DRIVE34: J70.5, S35.3, SW35.1, SW35.2, SW35.3, SW35.4, SW35.5, SW35.6, U35.3
DONE: J2.4, U1.4
DONE1: J4.4, U2.4
DONE2: J6.4, U3.4
DONE3: J8.4, U4.4
DONE4: J10.4, U5.4
DONE5: J12.4, U6.4
DONE6: J14.4, U7.4
DONE7: J16.4, U8.4
DONE8: J18.4, U9.4
DONE9: J20.4, U10.4
DONE10: J22.4, U11.4
DONE11: J24.4, U12.4
DONE12: J26.4, U13.4
DONE13: J28.4, U14.4
DONE14: J30.4, U15.4
DONE15: J32.4, U16.4
DONE16: J34.4, U17.4
DONE17: J36.4, U18.4
DONE18: J38.4, U19.4
DONE19: J40.4, U20.4
DONE20: J42.4, U21.4
DONE21: J44.4, U22.4
DONE22: J46.4, U23.4
DONE23: J48.4, U24.4
DONE24: J50.4, U25.4
DONE25: J52.4, U26.4
DONE26: J54.4, U27.4
DONE27: J56.4, U28.4
DONE28: J58.4, U29.4
DONE29: J60.4, U30.4
DONE30: J62.4, U31.4
DONE31: J64.4, U32.4
DONE32: J66.4, U33.4
DONE33: J68.4, U34.4
DONE34: J70.4, U35.4
GND: J1.1, J2.1, J2.3, R1.2, R2.2, R3.2, R4.2, R5.2, R6.1, R7.1, R8.P$2, U1.2
GND1: J3.1, J4.1, J4.3, R9.2, R10.2, R11.2, R12.2, R13.1, R14.1, R15.P$2, R16.2, U2.2
GND2: J5.1, J6.1, J6.3, R17.2, R18.2, R19.2, R20.2, R21.1, R22.1, R23.P$2, R24.2, U3.2
GND3: J7.1, J8.1, J8.3, R25.2, R26.2, R27.2, R28.2, R29.1, R30.1, R31.P$2, R32.2, U4.2
GND4: J9.1, J10.1, J10.3, R33.2, R34.2, R35.2, R36.2, R37.1, R38.1, R39.P$2, R40.2, U5.2
GND5: J11.1, J12.1, J12.3, R41.2, R42.2, R43.2, R44.2, R45.1, R46.1, R47.P$2, R48.2, U6.2
GND6: J13.1, J14.1, J14.3, R49.2, R50.2, R51.2, R52.2, R53.1, R54.1, R55.P$2, R56.2, U7.2
GND7: J15.1, J16.1, J16.3, R57.2, R58.2, R59.2, R60.2, R61.1, R62.1, R63.P$2, R64.2, U8.2
GND8: J17.1, J18.1, J18.3, R65.2, R66.2, R67.2, R68.2, R69.1, R70.1, R71.P$2, R72.2, U9.2
GND9: J19.1, J20.1, J20.3, R73.2, R74.2, R75.2, R76.2, R77.1, R78.1, R79.P$2, R80.2, U10.2
GND10: J21.1, J22.1, J22.3, R81.2, R82.2, R83.2, R84.2, R85.1, R86.1, R87.P$2, R88.2, U11.2
GND11: J23.1, J24.1, J24.3, R89.2, R90.2, R91.2, R92.2, R93.1, R94.1, R95.P$2, R96.2, U12.2
GND12: J25.1, J26.1, J26.3, R97.2, R98.2, R99.2, R100.2, R101.1, R102.1, R103.P$2, R104.2, U13.2
GND13: J27.1, J28.1, J28.3, R105.2, R106.2, R107.2, R108.2, R109.1, R110.1, R111.P$2, R112.2, U14.2
GND14: J29.1, J30.1, J30.3, R113.2, R114.2, R115.2, R116.2, R117.1, R118.1, R119.P$2, R120.2, U15.2
GND15: J31.1, J32.1, J32.3, R121.2, R122.2, R123.2, R124.2, R125.1, R126.1, R127.P$2, R128.2, U16.2
GND16: J33.1, J34.1, J34.3, R129.2, R130.2, R131.2, R132.2, R133.1, R134.1, R135.P$2, R136.2, U17.2
GND17: J35.1, J36.1, J36.3, R137.2, R138.2, R139.2, R140.2, R141.1, R142.1, R143.P$2, R144.2, U18.2
GND18: J37.1, J38.1, J38.3, R145.2, R146.2, R147.2, R148.2, R149.1, R150.1, R151.P$2, R152.2, U19.2
GND19: J39.1, J40.1, J40.3, R153.2, R154.2, R155.2, R156.2, R157.1, R158.1, R159.P$2, R160.2, U20.2
GND20: J41.1, J42.1, J42.3, R161.2, R162.2, R163.2, R164.2, R165.1, R166.1, R167.P$2, R168.2, U21.2
GND21: J43.1, J44.1, J44.3, R169.2, R170.2, R171.2, R172.2, R173.1, R174.1, R175.P$2, R176.2, U22.2
GND22: J45.1, J46.1, J46.3, R177.2, R178.2, R179.2, R180.2, R181.1, R182.1, R183.P$2, R184.2, U23.2
GND23: J47.1, J48.1, J48.3, R185.2, R186.2, R187.2, R188.2, R189.1, R190.1, R191.P$2, R192.2, U24.2
GND24: J49.1, J50.1, J50.3, R193.2, R194.2, R195.2, R196.2, R197.1, R198.1, R199.P$2, R200.2, U25.2
GND25: J51.1, J52.1, J52.3, R201.2, R202.2, R203.2, R204.2, R205.1, R206.1, R207.P$2, R208.2, U26.2
GND26: J53.1, J54.1, J54.3, R209.2, R210.2, R211.2, R212.2, R213.1, R214.1, R215.P$2, R216.2, U27.2
GND27: J55.1, J56.1, J56.3, R217.2, R218.2, R219.2, R220.2, R221.1, R222.1, R223.P$2, R224.2, U28.2
GND28: J57.1, J58.1, J58.3, R225.2, R226.2, R227.2, R228.2, R229.1, R230.1, R231.P$2, R232.2, U29.2
GND29: J59.1, J60.1, J60.3, R233.2, R234.2, R235.2, R236.2, R237.1, R238.1, R239.P$2, R240.2, U30.2
GND30: J61.1, J62.1, J62.3, R241.2, R242.2, R243.2, R244.2, R245.1, R246.1, R247.P$2, R248.2, U31.2
GND31: J63.1, J64.1, J64.3, R249.2, R250.2, R251.2, R252.2, R253.1, R254.1, R255.P$2, R256.2, U32.2
GND32: J65.1, J66.1, J66.3, R257.2, R258.2, R259.2, R260.2, R261.1, R262.1, R263.P$2, R264.2, U33.2
GND33: J67.1, J68.1, J68.3, R265.2, R266.2, R267.2, R268.2, R269.1, R270.1, R271.P$2, R272.2, U34.2
GND34: J69.1, J70.1, J70.3, R273.2, R274.2, R275.2, R276.2, R277.1, R278.1, R279.P$2, R280.2, U35.2
unnamed: D1.C, R6.2
unnamed: D2.C, R13.2
unnamed: R10.1, SW2.11
unnamed: R1.1, SW1.12
unnamed: R2.1, SW1.11
unnamed: R3.1, SW1.10
unnamed: R4.1, SW1.9
unnamed: R5.1, SW1.8
unnamed: R7.2, R8.P$1, SW1.7
unnamed: R16.1, SW2.10
unnamed: D1.A, JP2.1
unnamed: R14.2, R15.P$1, SW2.7
unnamed: R12.1, SW2.8
unnamed: R11.1, SW2.9
unnamed: R9.1, SW2.12
unnamed: D2.A, JP1.1
unnamed: D3.C, R21.2
unnamed: R18.1, SW3.11
unnamed: R24.1, SW3.10
unnamed: R22.2, R23.P$1, SW3.7
unnamed: R20.1, SW3.8
unnamed: R19.1, SW3.9
unnamed: R17.1, SW3.12
unnamed: D3.A, JP3.1
unnamed: D4.C, R29.2
unnamed: R26.1, SW4.11
unnamed: R32.1, SW4.10
unnamed: R30.2, R31.P$1, SW4.7
unnamed: R28.1, SW4.8
unnamed: R27.1, SW4.9
unnamed: R25.1, SW4.12
unnamed: D4.A, JP4.1
unnamed: D5.C, R37.2
unnamed: R34.1, SW5.11
unnamed: R40.1, SW5.10
unnamed: R38.2, R39.P$1, SW5.7
unnamed: R36.1, SW5.8
unnamed: R35.1, SW5.9
unnamed: R33.1, SW5.12
unnamed: D5.A, JP5.1
unnamed: D6.C, R45.2
unnamed: R42.1, SW6.11
unnamed: R48.1, SW6.10
unnamed: R46.2, R47.P$1, SW6.7
unnamed: R44.1, SW6.8
unnamed: R43.1, SW6.9
unnamed: R41.1, SW6.12
unnamed: D6.A, JP6.1
unnamed: D7.C, R53.2
unnamed: R50.1, SW7.11
unnamed: R56.1, SW7.10
unnamed: R54.2, R55.P$1, SW7.7
unnamed: R52.1, SW7.8
unnamed: R51.1, SW7.9
unnamed: R49.1, SW7.12
unnamed: D7.A, JP7.1
unnamed: D8.C, R61.2
unnamed: R58.1, SW8.11
unnamed: R64.1, SW8.10
unnamed: R62.2, R63.P$1, SW8.7
unnamed: R60.1, SW8.8
unnamed: R59.1, SW8.9
unnamed: R57.1, SW8.12
unnamed: D8.A, JP8.1
unnamed: D9.C, R69.2
unnamed: R66.1, SW9.11
unnamed: R72.1, SW9.10
unnamed: R70.2, R71.P$1, SW9.7
unnamed: R68.1, SW9.8
unnamed: R67.1, SW9.9
unnamed: R65.1, SW9.12
unnamed: D9.A, JP9.1
unnamed: D10.C, R77.2
unnamed: R74.1, SW10.11
unnamed: R80.1, SW10.10
unnamed: R78.2, R79.P$1, SW10.7
unnamed: R76.1, SW10.8
unnamed: R75.1, SW10.9
unnamed: R73.1, SW10.12
unnamed: D10.A, JP10.1
unnamed: D11.C, R85.2
unnamed: R82.1, SW11.11
unnamed: R88.1, SW11.10
unnamed: R86.2, R87.P$1, SW11.7
unnamed: R84.1, SW11.8
unnamed: R83.1, SW11.9
unnamed: R81.1, SW11.12
unnamed: D11.A, JP11.1
unnamed: D12.C, R93.2
unnamed: R90.1, SW12.11
unnamed: R96.1, SW12.10
unnamed: R94.2, R95.P$1, SW12.7
unnamed: R92.1, SW12.8
unnamed: R91.1, SW12.9
unnamed: R89.1, SW12.12
unnamed: D12.A, JP12.1
unnamed: D13.C, R101.2
unnamed: R98.1, SW13.11
unnamed: R104.1, SW13.10
unnamed: R102.2, R103.P$1, SW13.7
unnamed: R100.1, SW13.8
unnamed: R99.1, SW13.9
unnamed: R97.1, SW13.12
unnamed: D13.A, JP13.1
unnamed: D14.C, R109.2
unnamed: R106.1, SW14.11
unnamed: R112.1, SW14.10
unnamed: R110.2, R111.P$1, SW14.7
unnamed: R108.1, SW14.8
unnamed: R107.1, SW14.9
unnamed: R105.1, SW14.12
unnamed: D14.A, JP14.1
unnamed: D15.C, R117.2
unnamed: R114.1, SW15.11
unnamed: R120.1, SW15.10
unnamed: R118.2, R119.P$1, SW15.7
unnamed: R116.1, SW15.8
unnamed: R115.1, SW15.9
unnamed: R113.1, SW15.12
unnamed: D15.A, JP15.1
unnamed: D16.C, R125.2
unnamed: R122.1, SW16.11
unnamed: R128.1, SW16.10
unnamed: R126.2, R127.P$1, SW16.7
unnamed: R124.1, SW16.8
unnamed: R123.1, SW16.9
unnamed: R121.1, SW16.12
unnamed: D16.A, JP16.1
unnamed: D17.C, R133.2
unnamed: R130.1, SW17.11
unnamed: R136.1, SW17.10
unnamed: R134.2, R135.P$1, SW17.7
unnamed: R132.1, SW17.8
unnamed: R131.1, SW17.9
unnamed: R129.1, SW17.12
unnamed: D17.A, JP17.1
unnamed: D18.C, R141.2
unnamed: R138.1, SW18.11
unnamed: R144.1, SW18.10
unnamed: R142.2, R143.P$1, SW18.7
unnamed: R140.1, SW18.8
unnamed: R139.1, SW18.9
unnamed: R137.1, SW18.12
unnamed: D18.A, JP18.1
unnamed: D19.C, R149.2
unnamed: R146.1, SW19.11
unnamed: R152.1, SW19.10
unnamed: R150.2, R151.P$1, SW19.7
unnamed: R148.1, SW19.8
unnamed: R147.1, SW19.9
unnamed: R145.1, SW19.12
unnamed: D19.A, JP19.1
unnamed: D20.C, R157.2
unnamed: R154.1, SW20.11
unnamed: R160.1, SW20.10
unnamed: R158.2, R159.P$1, SW20.7
unnamed: R156.1, SW20.8
unnamed: R155.1, SW20.9
unnamed: R153.1, SW20.12
unnamed: D20.A, JP20.1
unnamed: D21.C, R165.2
unnamed: R162.1, SW21.11
unnamed: R168.1, SW21.10
unnamed: R166.2, R167.P$1, SW21.7
unnamed: R164.1, SW21.8
unnamed: R163.1, SW21.9
unnamed: R161.1, SW21.12
unnamed: D21.A, JP21.1
unnamed: D22.C, R173.2
unnamed: R170.1, SW22.11
unnamed: R176.1, SW22.10
unnamed: R174.2, R175.P$1, SW22.7
unnamed: R172.1, SW22.8
unnamed: R171.1, SW22.9
unnamed: R169.1, SW22.12
unnamed: D22.A, JP22.1
unnamed: D23.C, R181.2
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

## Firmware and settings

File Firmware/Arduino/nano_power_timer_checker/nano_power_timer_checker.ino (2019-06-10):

/*
  Example Code for the TPL5110 Nano Power Switch Hookup Guide. This code
  checks to see the exact time that is set by the switched resistor. This time
  varies by the EXACT resistance of the resistor which has a 1% tolerance. In
  addition, the datasheet clarifies that each resistance has its own margin of
  error when producing the given time at a given resistance. What does this
  mean? If you are in need of HIGH precision timing, this may not be the choice
  for you. If you're looking to decrease power consumption to increase battery
  life in remote applications, applications that don't require high sampling
  rates (less than 100ms), or some Internet of Things application, then you're in the right
  place. If you're using a 3.3V microcontroller then use a 3.3V power source,
  if you're using a 5V microcontroller then use a 5V souce. Take care to not
  BURN OUT your digital I/O. 
  SparkFun Electronics
  Date: May, 2019
  Author: Elias Santistevan
*/

/*  Hardware Setup on Redboard (Arduino): 
   - VDD_OUT -> 3 
   - GND -> GND 
   - VDD -> 3.3V 
*/

// REMEMBER - You must cycle power set new timer!
// ALSO - Press onboard button to begin cycle for long timers!
unsigned long endTimer = 0; 
unsigned long beginTimer = 0; 
float timerLength = 0; 

bool start = false; 
bool interrupted = false; 
// VDD-OUT goes is on pinCheck
int pinCheck = 3; 

void setup(){

  Serial.begin(115200); 
  Serial.println("Nano Power Switch - Timer Check!"); 
  Serial.println("Press the onboard button to begin the check.");
  pinMode(INPUT, pinCheck);
  // A interrupt may be overkill but it ensures we won't miss anything. 
  attachInterrupt(digitalPinToInterrupt(pinCheck), checkTimer, FALLING);

}

void loop(){

  // Check that timer is on! 
  if( (digitalRead(pinCheck) == HIGH) && (start == false)){ 
    Serial.print("Started: ");
    beginTimer = millis(); 
    Serial.println(beginTimer); 
    start = true; // Power is high, first flag is set. 
  }

  // If done signal is not sent back to Nano Power Switch, the Nano Power
  // Switch turns off power at the end of the timer anyway. After 50 ms the
  // Nano Power Switch will then turn the power back on. We're looking for that
  // small window when the power is turned off to calculate the exact time. 
  // Code will enter this block when timer has started (Power from VDD_out is
  // ON) and when we've seen it go low (Power from VDD_OUT is off).
  if((interrupted == true) && (start == true)){
    Serial.print("Ended: "); 
    Serial.println(endTimer);
    timerLength = endTimer - beginTimer; // Total time
    timerLength = timerLength + 50; // 50 ms off before back onto interval 
    Serial.print("Timer Length: "); 
    Serial.print(timerLength / 1000); // Convert to seconds... 
    Serial.println("-------");
    Serial.println();
    interrupted = false; 
    start = false; 
  }

}

// When power is low, we get our endTimer value, and set the second flag. 
void checkTimer(){
  endTimer = millis(); 
  interrupted = true; 
}

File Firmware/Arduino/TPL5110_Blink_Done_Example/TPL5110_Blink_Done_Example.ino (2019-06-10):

/*
  TPL5110_Blink_Demo_example.ino

  Simple Example Code for the TPL5110 Nano Power Timer Hookup Guide. This code
  simply blinks the pin 13 LED and writes pin 4 (donePin pin) high. This shift from
  LOW to HIGH of the donePin pin, signals to the Nano Power Timer to turn off the
  microcontroller.
  SparkFun Electronics
  Date: May, 2019
  Author: Elias Santistevan
*/

int led = 13; // Pin 13 LED
int donePin = 4; // Done pin - can be any pin.  

void setup(){

  pinMode(led, OUTPUT); 
  pinMode(donePin, OUTPUT); 

}

void loop(){
  // Blink. 
  digitalWrite(led, HIGH); 
  delay(1000); 
  digitalWrite(led, LOW); 
  delay(1000); 

  // We're done!
  // It's important that the donePin is written LOW and THEN HIGH. This shift
  // from low to HIGH is how the Nano Power Timer knows to turn off the
  // microcontroller. 
  digitalWrite(donePin, LOW); 
  digitalWrite(donePin, HIGH); 
  delay(10);
}

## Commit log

2019-05-06 Completes schematic and board design, adds buzzard labels
    [SparkFun_TPL5110_Breakout.brd, SparkFun_TPL5110_Breakout.sch]
2019-05-06 Updates buzzard labels, changes 5 pin header to 6 pin
    [SparkFun_TPL5110_Breakout.brd, SparkFun_TPL5110_Breakout.sch]
2019-05-06 Adds additional labels to switches, increases trace width of VDD
    [SparkFun_TPL5110_Breakout.brd]
2019-05-06 Adds bare file of resistor calculator script for determining delay
2019-05-06 Adds some bare functions to resistor_calculator function
2019-05-07 Alignes swtich silk, adds "in/out" silk, increases size of product name silk
    [SparkFun_TPL5110_Breakout.brd, SparkFun_TPL5110_Breakout.sch]
2019-05-07 Adds final resistor values: 93.1k, 124k, 169k, Updates python script so that user can calculate combinations with 6th custom resistor
    [SparkFun_TPL5110_Breakout.brd, SparkFun_TPL5110_Breakout.sch]
2019-05-07 Adds Production Files and adds text to custom resistors
    [SparkFun_TPL5110_Breakout-Panel.brd, SparkFun_TPL5110_Breakout.sch]
2019-05-08 Moves Production Files to main file structure, updates board file and resistor calculator readme
    [SparkFun_TPL5110_Breakout-Panel.brd]
2019-05-08 Renames boad and schematic files to avoid confusion
    [SparkFun_TPL5110_Nano_Power_Switch.brd, SparkFun_TPL5110_Nano_Power_Switch.sch]
2019-05-15 Switches gate and source nets, attaches LED to VDD_OUT, adds "+" and "-" silk to board
    [SparkFun_TPL5110_Nano_Power_Switch.brd, SparkFun_TPL5110_Nano_Power_Switch.sch]
2019-06-10 Update Firmware Examples
    - Separate TPL5110 Python Script from Arduino examples
    - Add example used in tutorial to toggle TPL5110's Done pin
2019-07-16 Removes resistance calculator

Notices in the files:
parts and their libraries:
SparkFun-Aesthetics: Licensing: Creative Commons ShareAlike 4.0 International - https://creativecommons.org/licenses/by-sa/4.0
